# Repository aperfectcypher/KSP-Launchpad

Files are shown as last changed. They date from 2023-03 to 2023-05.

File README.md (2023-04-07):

# KSP-Launchpad
## THIS IS AN EARLY WORK IN PROGRESS

Firmware for the KSP-Launchpad board.

MCU is an ATmega2560.
## Features

* Dual 3-axis joystick for rotation and translation
* Linear potentiometers for throttle
* SAS LED
* RCS LED
* LED bars as ship ressources gauges
* LCD screen (128x32px) for ship status

## Schematics

The schematics are written using kicad.
The schematics are available in the `schematics` directory.

## License

The firmware and schematics are licensed under the Unlicense license.

## Author

[Aperfectcypher](https://github.com/aperfectcypher)

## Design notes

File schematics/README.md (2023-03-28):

# Schematics
The schematics are written using kicad.

Required libraries:
* [Connectors_JST](https://github.com/KiCad/Connectors_JST.pretty)

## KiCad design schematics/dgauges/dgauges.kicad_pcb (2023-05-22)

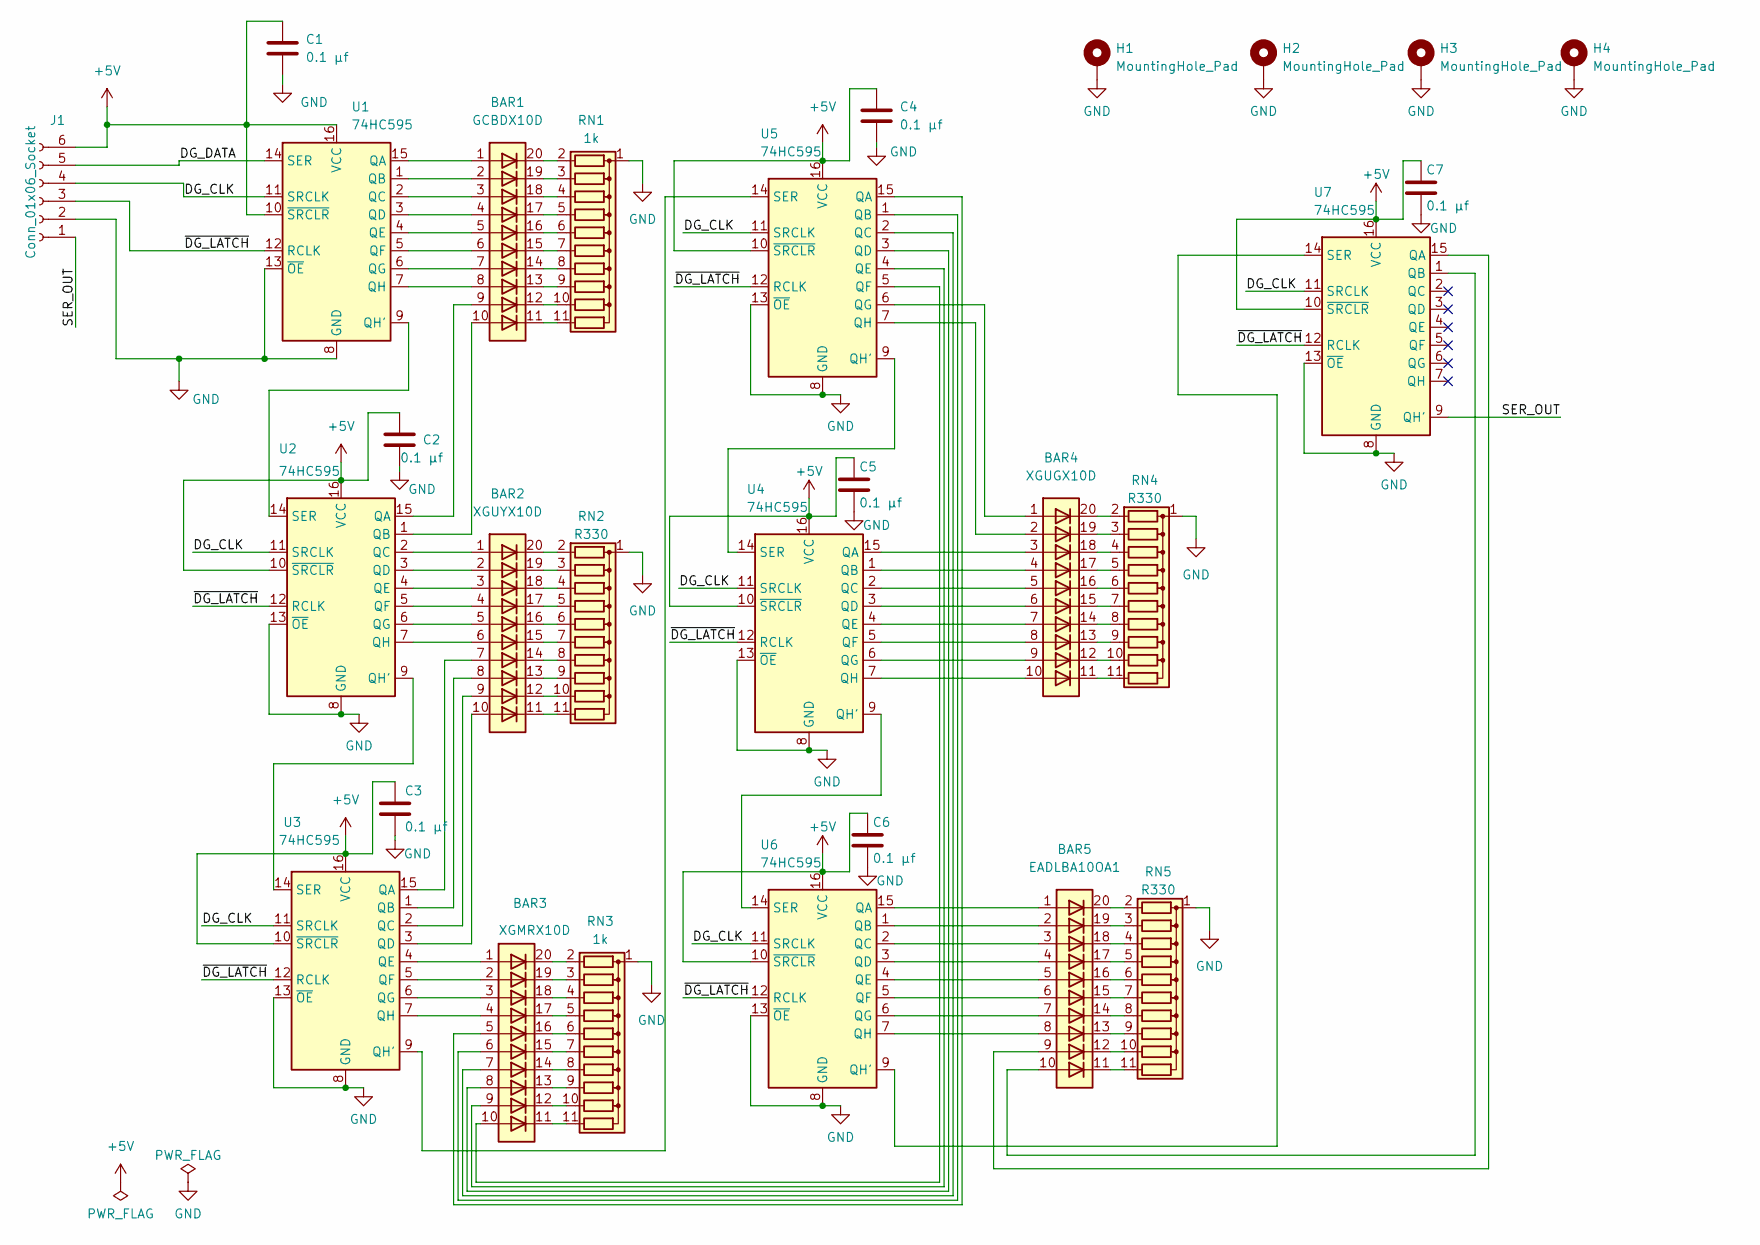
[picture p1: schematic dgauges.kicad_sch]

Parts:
BAR1: GCBDX10D; HDSP-4832
BAR2: XGUYX10D; HDSP-4832
BAR3: XGMRX10D; HDSP-4832
BAR4: XGUGX10D; HDSP-4832
BAR5: EADLBA10OA1; HDSP-4832
C1, C2, C3, C4, C5, C6, C7: 0.1 µf; C_Disc_D4.3mm_W1.9mm_P5.00mm; LCSC C254085
H1, H2, H3, H4: MountingHole_Pad; MountingHole_2.2mm_M2_ISO7380_Pad
J1: Conn_01x06_Socket; JST_PH_B6B-PH-K_1x06_P2.00mm_Vertical
RN1, RN3: 1k; R_Array_SIP11; digikey 4611X-101-102LF-ND
RN2, RN4, RN5: R330; R_Array_SIP11; digi-key 4611X-101-331LF
U1, U2, U3, U4, U5, U6, U7: 74HC595; DIP-16_W7.62mm

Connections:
+5V: C1.1, C2.1, C3.1, C4.1, C5.1, C6.1, C7.1, J1.6, U1.10 (~SRCLR), U1.16 (VCC), U2.10 (~SRCLR), U2.16 (VCC), U3.10 (~SRCLR), U3.16 (VCC), U4.10 (~SRCLR), U4.16 (VCC), U5.10 (~SRCLR), U5.16 (VCC), U6.10 (~SRCLR), U6.16 (VCC), U7.10 (~SRCLR), U7.16 (VCC)
/DG_CLK: J1.4, U1.11 (SRCLK), U2.11 (SRCLK), U3.11 (SRCLK), U4.11 (SRCLK), U5.11 (SRCLK), U6.11 (SRCLK), U7.11 (SRCLK)
/DG_DATA: J1.5, U1.14 (SER)
/SER_OUT: J1.1, U7.9 (QH')
/~DG_LATCH: J1.3, U1.12 (RCLK), U2.12 (RCLK), U3.12 (RCLK), U4.12 (RCLK), U5.12 (RCLK), U6.12 (RCLK), U7.12 (RCLK)
GND: C1.2, C2.2, C3.2, C4.2, C5.2, C6.2, C7.2, H1.1, H2.1, H3.1, H4.1, J1.2, RN1.1 (common), RN2.1 (common), RN3.1 (common), RN4.1 (common), RN5.1 (common), U1.8 (GND), U1.13 (~OE), U2.8 (GND), U2.13 (~OE), U3.8 (GND), U3.13 (~OE), U4.8 (GND), U4.13 (~OE), U5.8 (GND), U5.13 (~OE), U6.8 (GND), U6.13 (~OE), U7.8 (GND), U7.13 (~OE)
unnamed: BAR1.20 (K), RN1.2 (R1)
unnamed: BAR1.19 (K), RN1.3 (R2)
unnamed: BAR1.18 (K), RN1.4 (R3)
unnamed: BAR1.17 (K), RN1.5 (R4)
unnamed: BAR1.16 (K), RN1.6 (R5)
unnamed: BAR1.15 (K), RN1.7 (R6)
unnamed: BAR1.14 (K), RN1.8 (R7)
unnamed: BAR1.13 (K), RN1.9 (R8)
unnamed: BAR1.12 (K), RN1.10 (R9)
unnamed: BAR1.11 (K), RN1.11 (R10)
unnamed: BAR2.20 (K), RN2.2 (R1)
unnamed: BAR2.19 (K), RN2.3 (R2)
unnamed: BAR2.18 (K), RN2.4 (R3)
unnamed: BAR2.17 (K), RN2.5 (R4)
unnamed: BAR2.16 (K), RN2.6 (R5)
unnamed: BAR2.15 (K), RN2.7 (R6)
unnamed: BAR2.14 (K), RN2.8 (R7)
unnamed: BAR2.13 (K), RN2.9 (R8)
unnamed: BAR2.12 (K), RN2.10 (R9)
unnamed: BAR2.11 (K), RN2.11 (R10)
unnamed: BAR3.20 (K), RN3.2 (R1)
unnamed: BAR3.19 (K), RN3.3 (R2)
unnamed: BAR3.18 (K), RN3.4 (R3)
unnamed: BAR3.17 (K), RN3.5 (R4)
unnamed: BAR3.16 (K), RN3.6 (R5)
unnamed: BAR3.15 (K), RN3.7 (R6)
unnamed: BAR3.14 (K), RN3.8 (R7)
unnamed: BAR3.13 (K), RN3.9 (R8)
unnamed: BAR3.12 (K), RN3.10 (R9)
unnamed: BAR3.11 (K), RN3.11 (R10)
unnamed: BAR4.20 (K), RN4.2 (R1)
unnamed: BAR4.19 (K), RN4.3 (R2)
unnamed: BAR4.18 (K), RN4.4 (R3)
unnamed: BAR4.17 (K), RN4.5 (R4)
unnamed: BAR4.16 (K), RN4.6 (R5)
unnamed: BAR4.15 (K), RN4.7 (R6)
unnamed: BAR4.14 (K), RN4.8 (R7)
unnamed: BAR4.13 (K), RN4.9 (R8)
unnamed: BAR4.12 (K), RN4.10 (R9)
unnamed: BAR4.11 (K), RN4.11 (R10)
unnamed: BAR5.20 (K), RN5.2 (R1)
unnamed: BAR5.19 (K), RN5.3 (R2)
unnamed: BAR5.18 (K), RN5.4 (R3)
unnamed: BAR5.17 (K), RN5.5 (R4)
unnamed: BAR5.16 (K), RN5.6 (R5)
unnamed: BAR5.15 (K), RN5.7 (R6)
unnamed: BAR5.14 (K), RN5.8 (R7)
unnamed: BAR5.13 (K), RN5.9 (R8)
unnamed: BAR5.12 (K), RN5.10 (R9)
unnamed: BAR5.11 (K), RN5.11 (R10)
unnamed: BAR1.1 (A), U1.15 (QA)
unnamed: BAR1.2 (A), U1.1 (QB)
unnamed: BAR1.3 (A), U1.2 (QC)
unnamed: BAR1.4 (A), U1.3 (QD)
unnamed: BAR1.5 (A), U1.4 (QE)
unnamed: BAR1.6 (A), U1.5 (QF)
unnamed: BAR1.7 (A), U1.6 (QG)
unnamed: U1.9 (QH'), U2.14 (SER)
unnamed: BAR1.8 (A), U1.7 (QH)
unnamed: BAR1.9 (A), U2.15 (QA)
unnamed: BAR1.10 (A), U2.1 (QB)
unnamed: BAR2.1 (A), U2.2 (QC)
unnamed: BAR2.2 (A), U2.3 (QD)
unnamed: BAR2.3 (A), U2.4 (QE)
unnamed: BAR2.4 (A), U2.5 (QF)
unnamed: BAR2.5 (A), U2.6 (QG)
unnamed: U2.9 (QH'), U3.14 (SER)
unnamed: BAR2.6 (A), U2.7 (QH)
unnamed: BAR2.7 (A), U3.15 (QA)
unnamed: BAR2.8 (A), U3.1 (QB)
unnamed: BAR2.9 (A), U3.2 (QC)
unnamed: BAR2.10 (A), U3.3 (QD)
unnamed: BAR3.1 (A), U3.4 (QE)
unnamed: BAR3.2 (A), U3.5 (QF)
unnamed: BAR3.3 (A), U3.6 (QG)
unnamed: U3.9 (QH'), U5.14 (SER)
unnamed: BAR3.4 (A), U3.7 (QH)
unnamed: BAR4.3 (A), U4.15 (QA)
unnamed: BAR4.4 (A), U4.1 (QB)
unnamed: BAR4.5 (A), U4.2 (QC)
unnamed: BAR4.6 (A), U4.3 (QD)
unnamed: BAR4.7 (A), U4.4 (QE)
unnamed: BAR4.8 (A), U4.5 (QF)
unnamed: BAR4.9 (A), U4.6 (QG)
unnamed: U4.9 (QH'), U6.14 (SER)
unnamed: BAR4.10 (A), U4.7 (QH)
unnamed: U4.14 (SER), U5.9 (QH')
unnamed: BAR3.5 (A), U5.15 (QA)
unnamed: BAR3.6 (A), U5.1 (QB)
unnamed: BAR3.7 (A), U5.2 (QC)
unnamed: BAR3.8 (A), U5.3 (QD)
unnamed: BAR3.9 (A), U5.4 (QE)
unnamed: BAR3.10 (A), U5.5 (QF)
unnamed: BAR4.1 (A), U5.6 (QG)
unnamed: BAR4.2 (A), U5.7 (QH)
unnamed: BAR5.1 (A), U6.15 (QA)
unnamed: BAR5.2 (A), U6.1 (QB)
unnamed: BAR5.3 (A), U6.2 (QC)
unnamed: BAR5.4 (A), U6.3 (QD)
unnamed: BAR5.5 (A), U6.4 (QE)
unnamed: BAR5.6 (A), U6.5 (QF)
unnamed: BAR5.7 (A), U6.6 (QG)
unnamed: U6.9 (QH'), U7.14 (SER)
unnamed: BAR5.8 (A), U6.7 (QH)
unnamed: BAR5.9 (A), U7.15 (QA)
unnamed: BAR5.10 (A), U7.1 (QB)

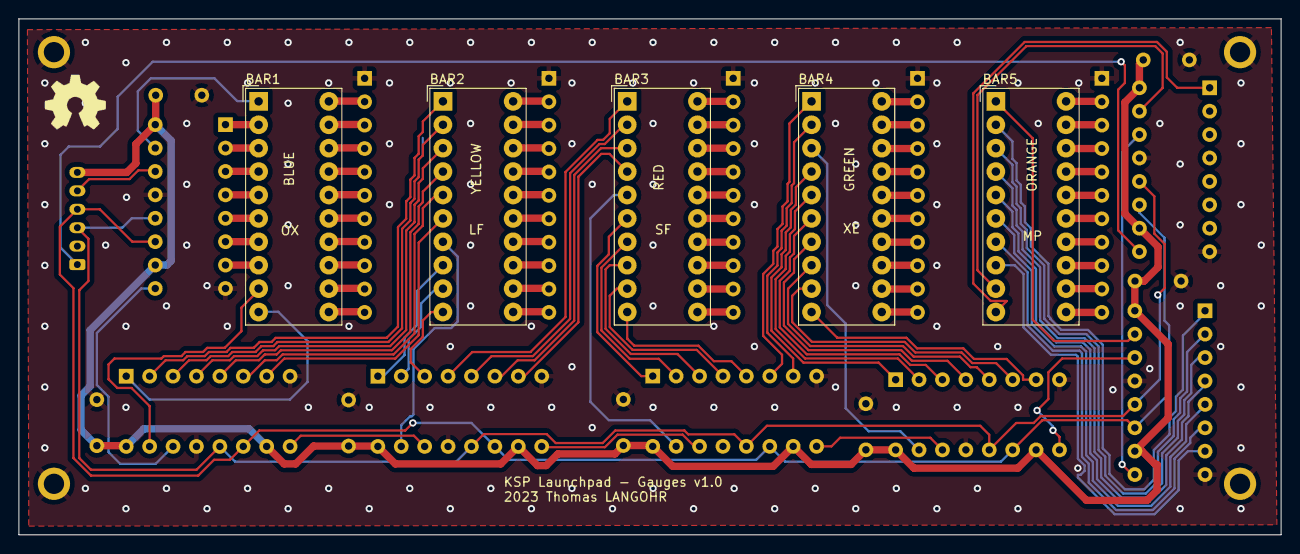
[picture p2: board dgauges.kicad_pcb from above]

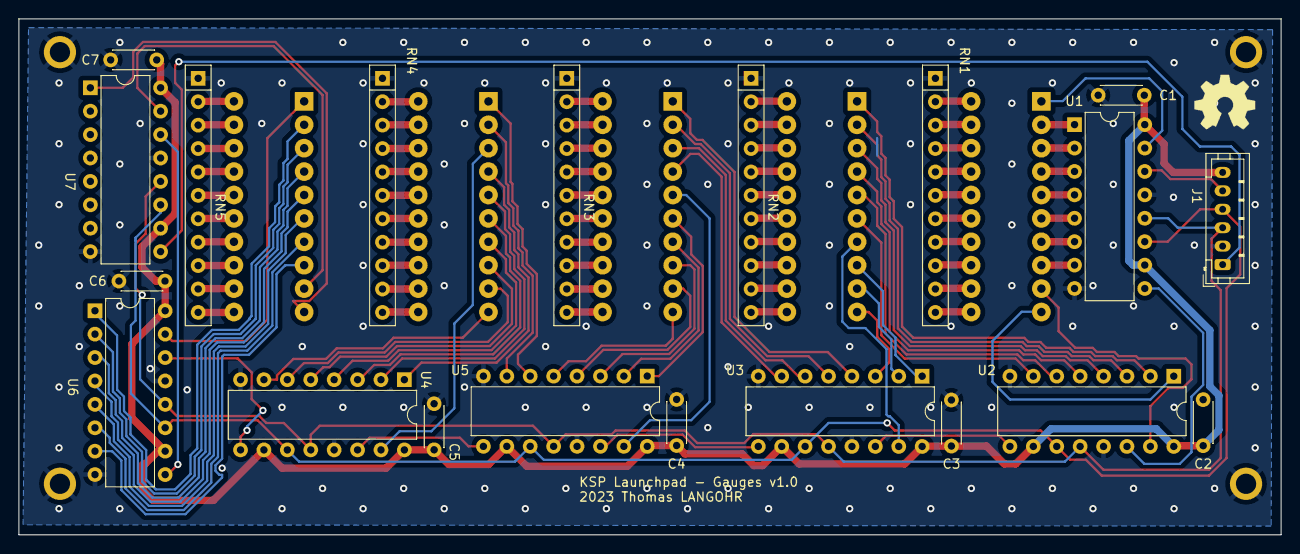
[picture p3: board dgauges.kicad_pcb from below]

Board: 2 copper layers, 137.0 x 56.0 mm, 29 parts (20 on the bottom side), 112 nets.

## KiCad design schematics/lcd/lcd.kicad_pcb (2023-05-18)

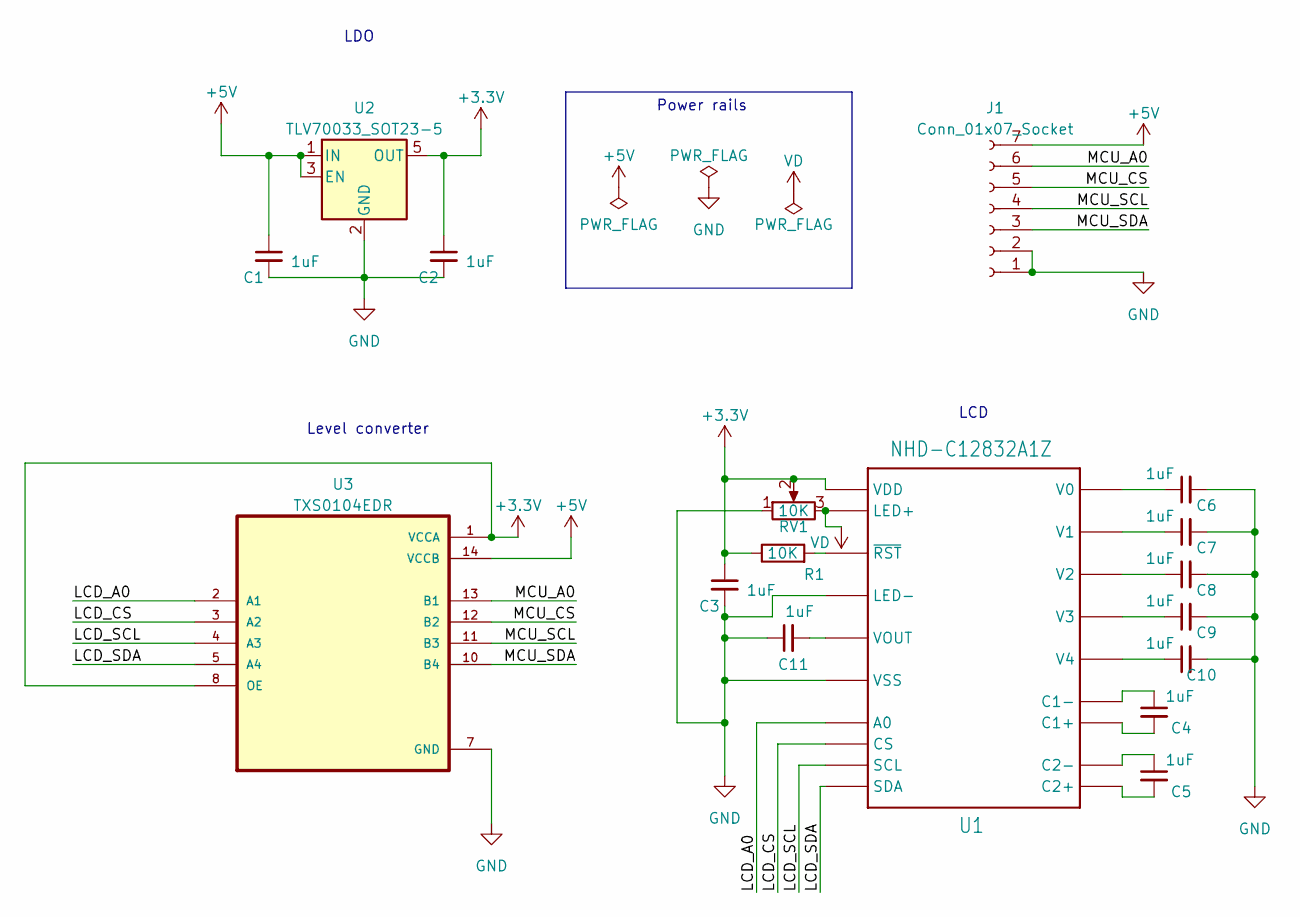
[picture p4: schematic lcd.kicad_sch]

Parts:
C1, C2, C3, C4, C5, C6, C7, C8, C9, C10, C11: 1uF; C_0603_1608Metric; lcsc C59302
J1: Conn_01x07_Socket; JST_PH_B7B-PH-K_1x07_P2.00mm_Vertical
R1: 10K; R_0603_1608Metric; lcsc C25804
RV1: 10K; Potentiometer_Bourns_3314G_Vertical; lcsc C780220
U1: NHD-C12832A1Z; JLCPCB BOM 0
U2: TLV70033_SOT23-5; SOT-23-5
U3: TXS0104EDR; SOIC127P600X175-14N; LCSC C79342

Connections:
+3.3V: C2.1, C3.1, R1.1, RV1.2, U1.P12 (VDD), U2.5 (OUT), U3.1 (VCCA), U3.8 (OE)
+5V: C1.1, J1.7, U2.1 (IN), U2.3 (EN), U3.14 (VCCB)
/LCD_A0: U1.P15 (A0), U3.2 (A1)
/LCD_CS: U1.P17 (CS), U3.3 (A2)
/LCD_SCL: U1.P14 (SCL), U3.4 (A3)
/LCD_SDA: U1.P13 (SDA), U3.5 (A4)
/MCU_A0: J1.6, U3.13 (B1)
/MCU_CS: J1.5, U3.12 (B2)
/MCU_SCL: J1.4, U3.11 (B3)
/MCU_SDA: J1.3, U3.10 (B4)
GND: C1.2, C2.2, C3.2, C6.2, C7.2, C8.2, C9.2, C10.2, C11.1, J1.1, J1.2, RV1.1, U1.P11 (VSS), U1.P19 (LED-), U2.2 (GND), U3.7 (GND)
unnamed: C4.2, U1.P8 (C1+)
unnamed: C4.1, U1.P9 (C1-)
unnamed: C5.2, U1.P7 (C2+)
unnamed: C5.1, U1.P6 (C2-)
unnamed: C6.1, U1.P1 (V0)
unnamed: C7.1, U1.P2 (V1)
unnamed: C8.1, U1.P3 (V2)
unnamed: C9.1, U1.P4 (V3)
unnamed: C10.1, U1.P5 (V4)
unnamed: C11.2, U1.P10 (VOUT)
unnamed: R1.2, U1.P16 (~RST)
VD: RV1.3, U1.P18 (LED+)

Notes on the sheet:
LCD
Level converter
Power rails
LDO

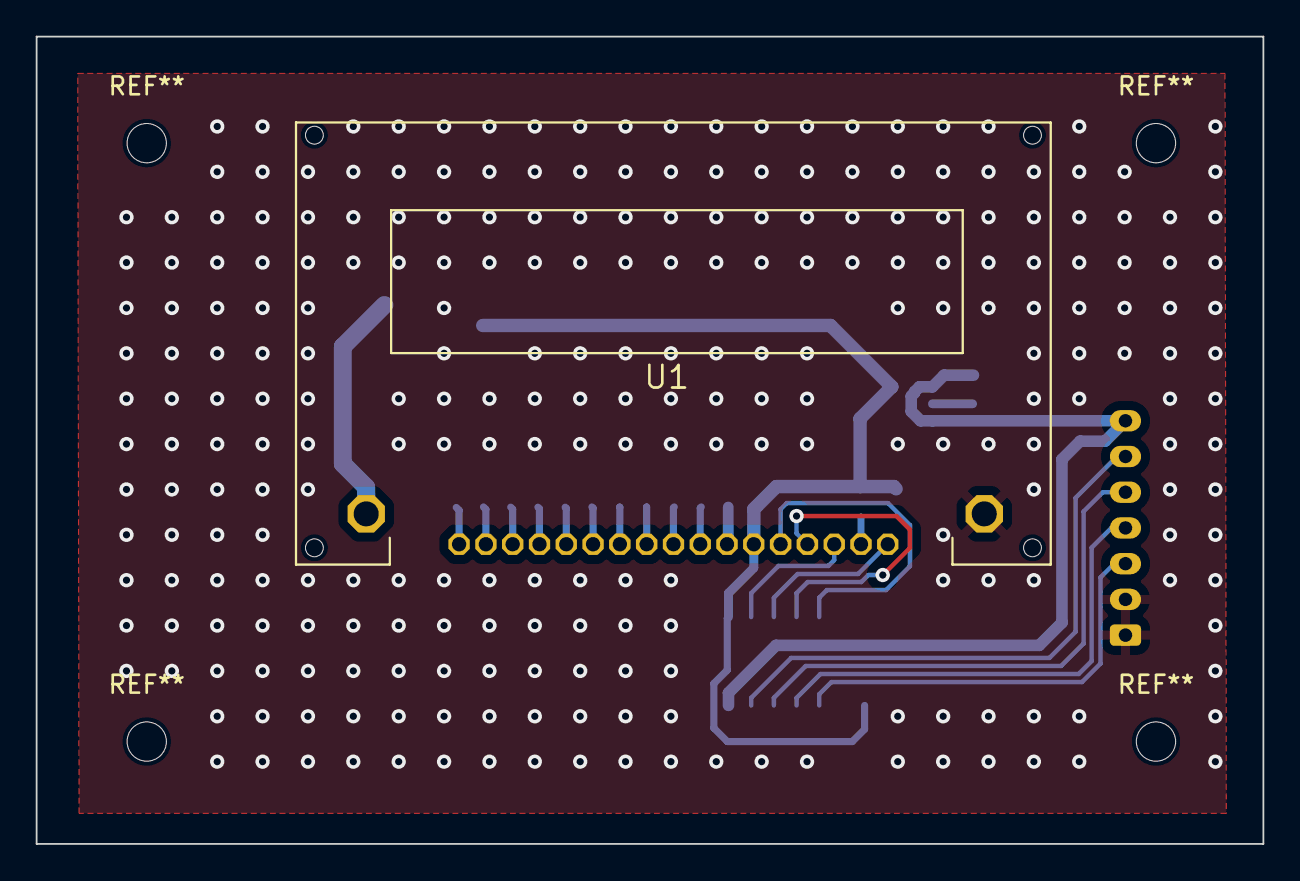
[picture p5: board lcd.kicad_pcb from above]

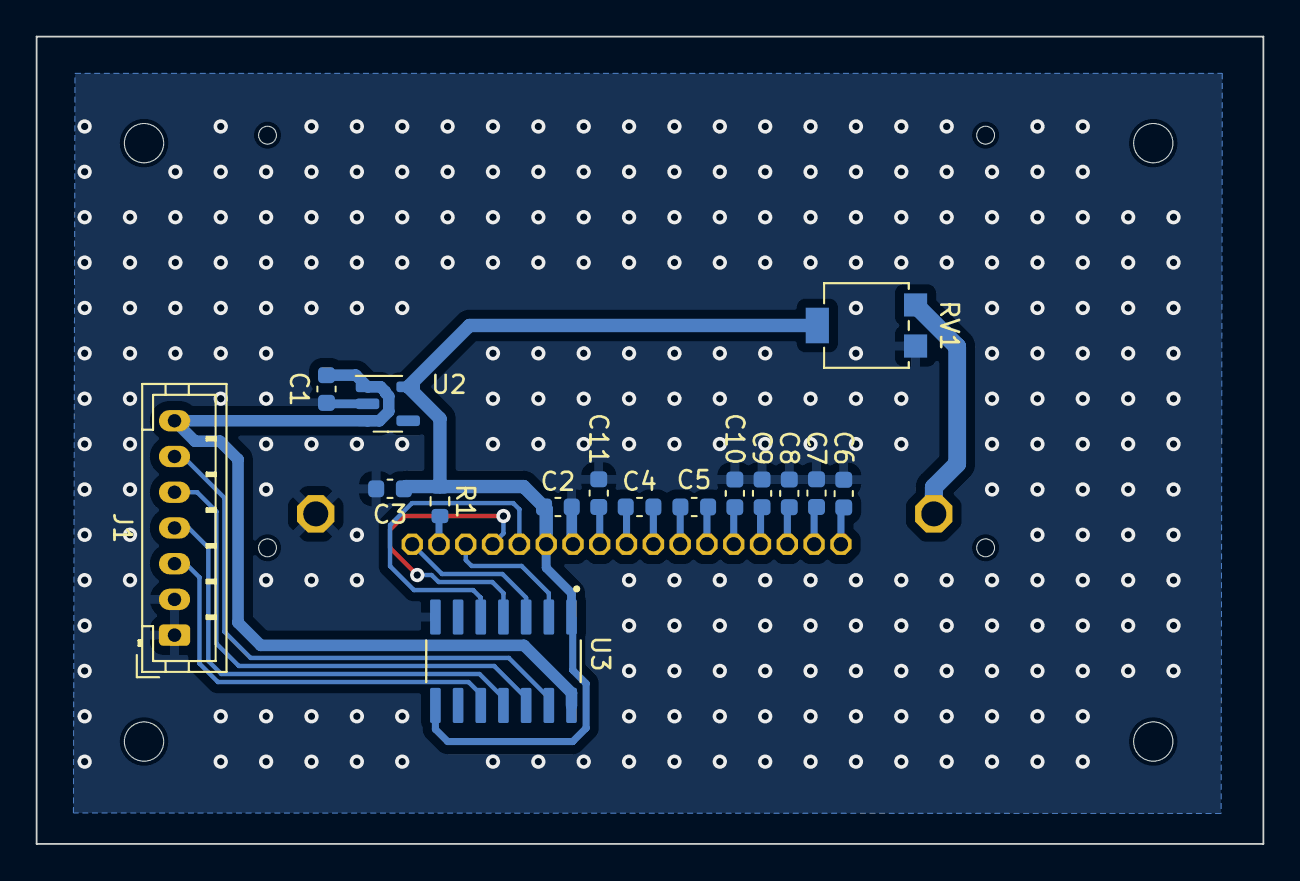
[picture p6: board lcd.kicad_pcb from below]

Board: 2 copper layers, 68.7 x 45.2 mm, 17 parts (16 on the bottom side), 23 nets.

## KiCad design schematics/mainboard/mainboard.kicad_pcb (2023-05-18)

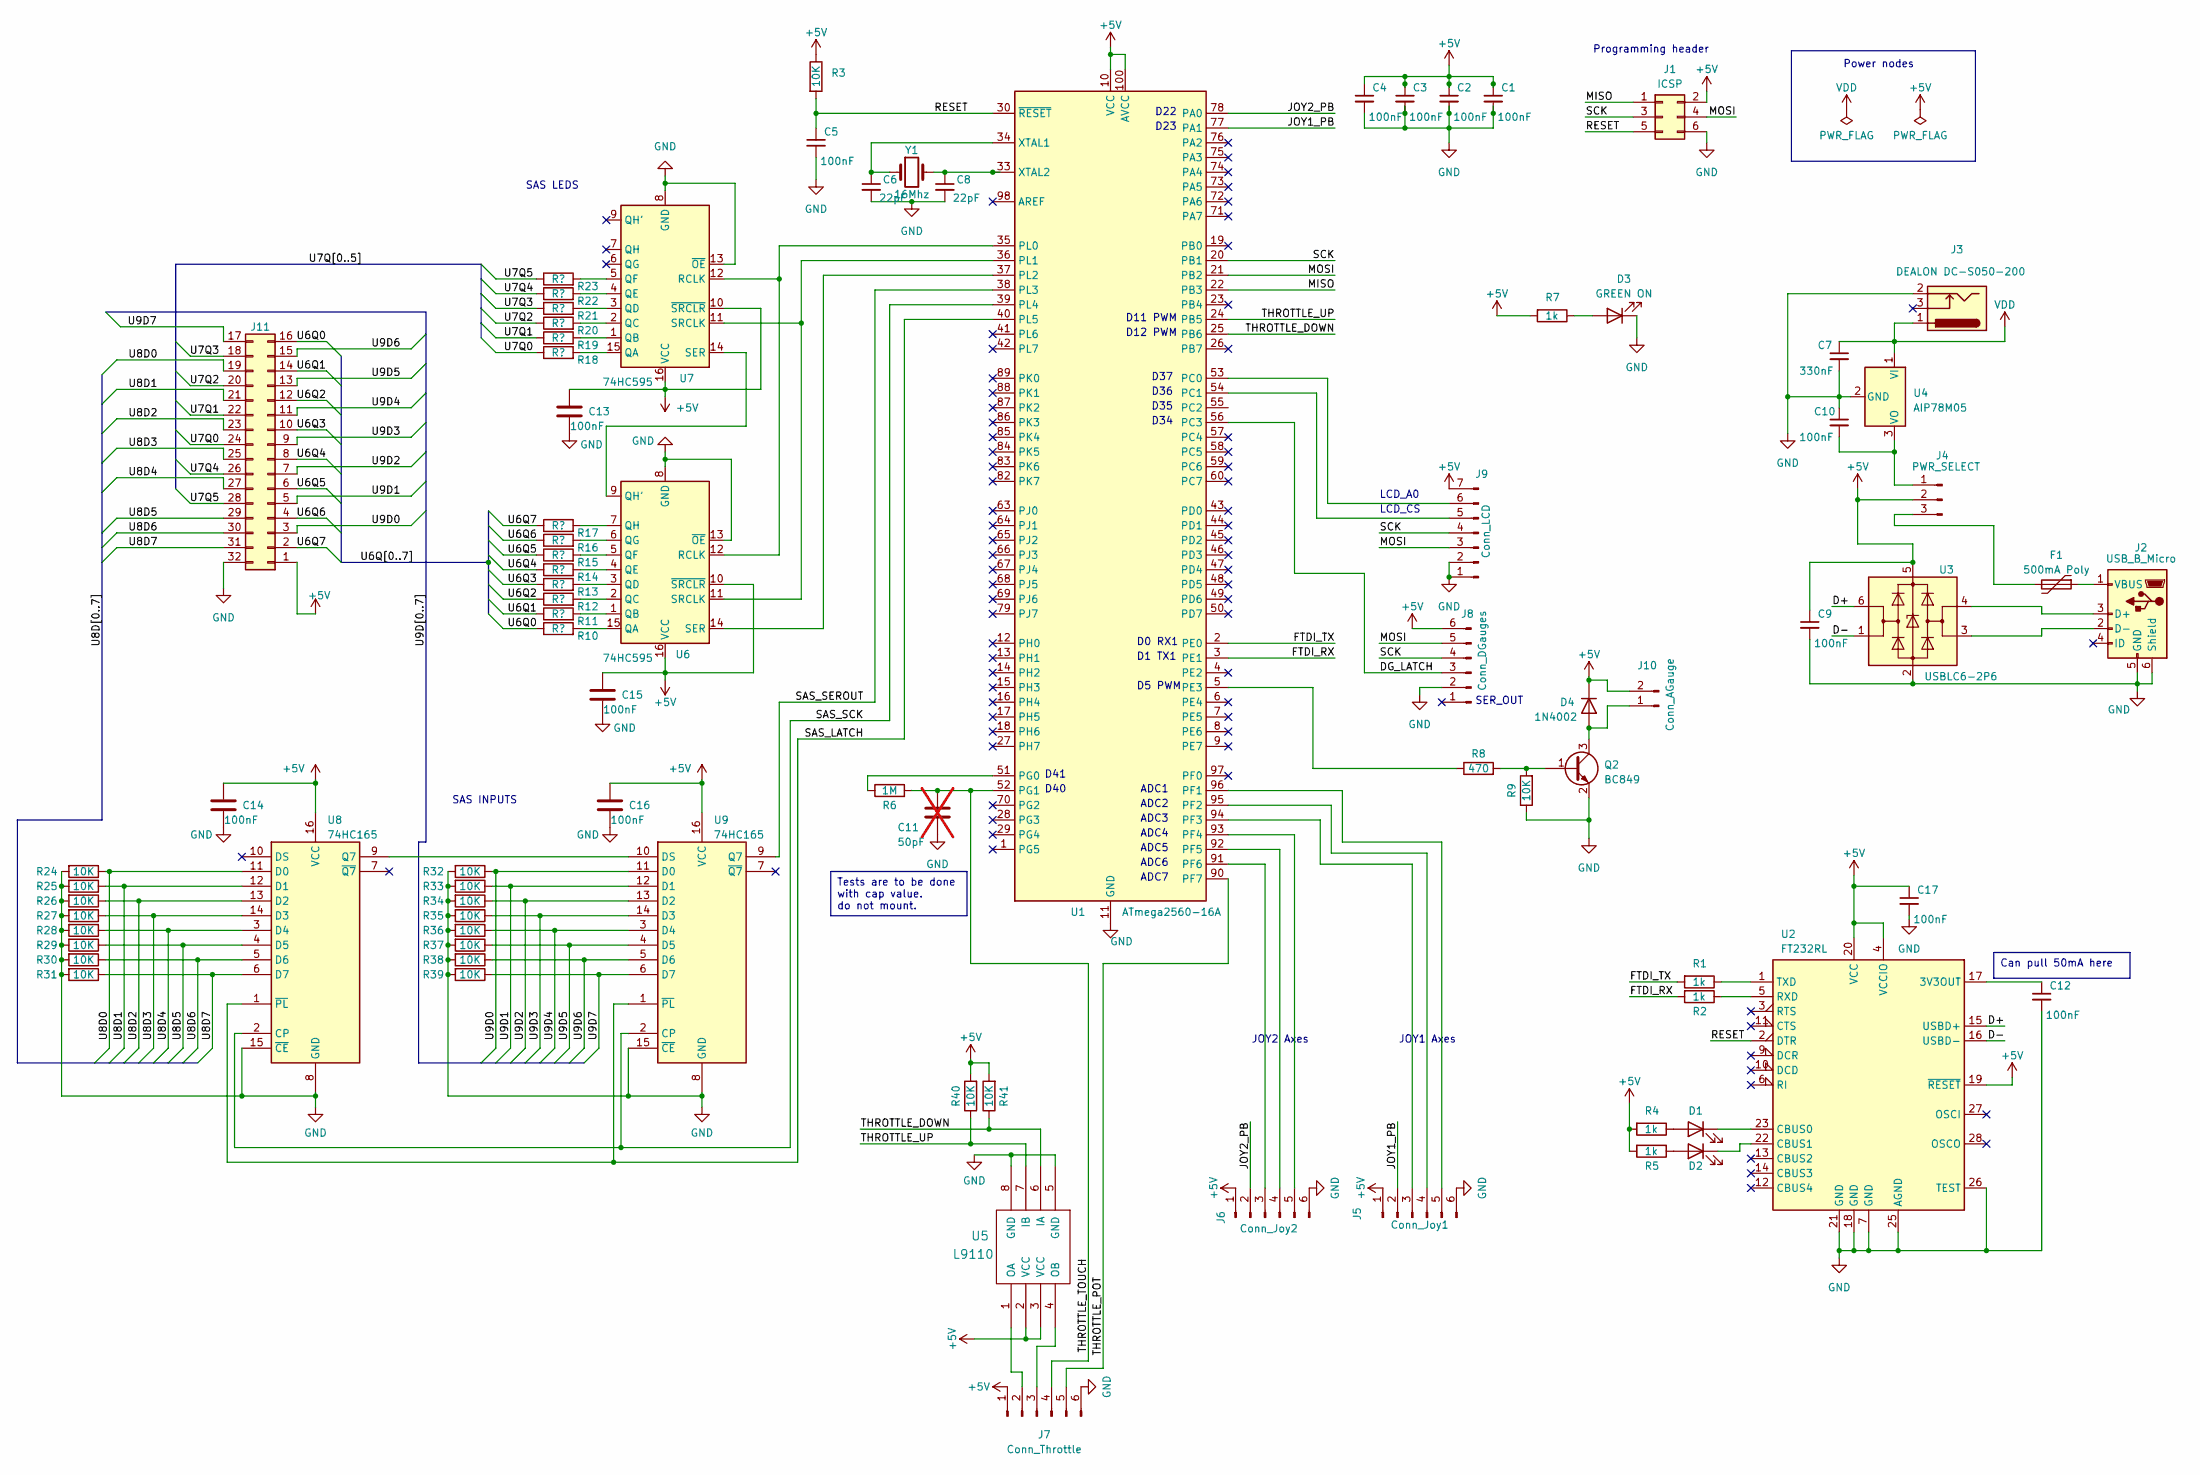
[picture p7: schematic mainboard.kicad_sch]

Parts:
C1, C2, C3, C4, C5, C9, C12, C17: 100nF; C_0603_1608Metric; lcsc C30926
C6, C8: 22pF; C_0603_1608Metric; lcsc C105620
C7: 330nF; C_0603_1608Metric; lcsc C282682
C10: 100nF; C_0603_1608Metric; lcsc C14665
C11: 50pF; C_0603_1608Metric; not fitted
C13, C14, C15, C16: 100nF; C_0603_1608Metric
D1, D2: LED; LED_1206_3216Metric
D3: GREEN ON; LED_0603_1608Metric
D4: 1N4002; D_SOD-123F; lcsc C169542
F1: 500mA Poly; Fuse_0603_1608Metric; lcsc C311055
J1: ICSP; PinHeader_2x03_P2.54mm_Vertical
J2: USB_B_Micro; USB_Micro-B_Molex-105017-0001; lcsc C962222
J3: DEALON DC-S050-200; BarrelJack_CLIFF_FC681465S_SMT_Horizontal; lcsc C2936010
J4: PWR_SELECT; PinHeader_1x03_P2.54mm_Vertical
J5: Conn_Joy1; JST_PH_B6B-PH-K_1x06_P2.00mm_Vertical
J6: Conn_Joy2; JST_PH_B6B-PH-K_1x06_P2.00mm_Vertical
J7: Conn_Throttle; JST_PH_B6B-PH-K_1x06_P2.00mm_Vertical
J8: Conn_DGauges; JST_PH_B6B-PH-K_1x06_P2.00mm_Vertical
J9: Conn_LCD; JST_PH_B7B-PH-K_1x07_P2.00mm_Vertical
J10: Conn_AGauge; JST_PH_B2B-PH-K_1x02_P2.00mm_Vertical
J11: Conn_SAS; JST_PHD_B32B-PHDSS_2x16_P2.00mm_Vertical; lcsc C1121898
Q2: BC849; SOT-23; lcsc C475633
R1, R2, R4, R5, R7: 1k; R_0603_1608Metric; lcsc C21190
R3: 10K; R_0603_1608Metric; lcsc C25804
R6: 1M; R_0603_1608Metric
R8: 470; R_0603_1608Metric
R9, R24, R25, R26, R27, R28, R29, R30, R31, R32, R33, R34, R35, R36, R37, R38, R39, R40, R41: 10K; R_0603_1608Metric
R10, R11, R12, R13, R14, R15, R16, R17, R18, R19, R20, R21, R22, R23: R?; R_0603_1608Metric
U1: ATmega2560-16A; TQFP-100_14x14mm_P0.5mm; lcsc C22460
U2: FT232RL; SSOP-28_3.9x9.9mm_P0.635mm
U3: USBLC6-2P6; SOT-666; lcsc C15999
U4: AIP78M05; TO-252-2; lcsc C3019178
U5: L9110; DIP-8_W7.62mm_Socket
U6, U7: 74HC595; DIP-16_W7.62mm
U8, U9: 74HC165; DIP-16_W7.62mm
Y1: 16Mhz; Crystal_SMD_5032-2Pin_5.0x3.2mm; lcsc C112572

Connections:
+5V: C1.1, C2.1, C3.1, C4.1, C9.1, C13.1, C14.1, C15.1, C16.1, C17.1, D4.1 (K), J1.2, J4.2, J5.1, J6.1, J7.1, J8.6, J9.7, J10.2, J11.1, R3.1, R4.2, R5.2, R7.2, R40.2, R41.2, U1.10 (VCC), U1.31 (VCC), U1.61 (VCC), U1.80 (VCC), U1.100 (AVCC), U2.4 (VCCIO), U2.19 (~RESET), U2.20 (VCC), U3.5 (VBUS), U5.2 (VCC), U5.3 (VCC), U6.10 (~SRCLR), U6.16 (VCC), U7.10 (~SRCLR), U7.16 (VCC), U8.16 (VCC), U9.16 (VCC)
/D+: U2.15 (USBD+), U3.6 (I/O1)
/D-: U2.16 (USBD-), U3.1 (I/O1)
/DG_LATCH: J8.3, U1.56 (PC3)
/FTDI_RX: R2.2, U1.3 (PE1)
/FTDI_TX: R1.2, U1.2 (PE0)
/JOY1_PB: J5.2, U1.77 (PA1)
/JOY2_PB: J6.2, U1.78 (PA0)
/MISO: J1.1, U1.22 (PB3)
/MOSI: J1.4, J8.5, J9.3, U1.21 (PB2)
/RESET: C5.1, J1.5, R3.2, U1.30 (~RESET), U2.2 (DTR)
/SAS_LATCH: U1.40 (PL5), U8.1 (~PL), U9.1 (~PL)
/SAS_SCK: U1.39 (PL4), U8.2 (CP), U9.2 (CP)
/SAS_SEROUT: U1.38 (PL3), U9.9 (Q7)
/SCK: J1.3, J8.4, J9.4, U1.20 (PB1)
/THROTTLE_DOWN: R41.1, U1.25 (PB6), U5.6 (IA)
/THROTTLE_POT: J7.5, U1.90 (PF7)
/THROTTLE_TOUCH: C11.1, J7.4, R6.2, U1.52 (PG1)
/THROTTLE_UP: R40.1, U1.24 (PB5), U5.7 (IB)
/U6Q0: J11.16, R10.1
/U6Q1: J11.14, R11.1
/U6Q2: J11.12, R12.1
/U6Q3: J11.10, R13.1
/U6Q4: J11.8, R14.1
/U6Q5: J11.6, R15.1
/U6Q6: J11.4, R16.1
/U6Q7: J11.2, R17.1
/U7Q0: J11.24, R18.1
/U7Q1: J11.22, R19.1
/U7Q2: J11.20, R20.1
/U7Q3: J11.18, R21.1
/U7Q4: J11.26, R22.1
/U7Q5: J11.28, R23.1
/U8D0: J11.19, R24.1, U8.11 (D0)
/U8D1: J11.21, R25.1, U8.12 (D1)
/U8D2: J11.23, R26.1, U8.13 (D2)
/U8D3: J11.25, R27.1, U8.14 (D3)
/U8D4: J11.27, R28.1, U8.3 (D4)
/U8D5: J11.29, R29.1, U8.4 (D5)
/U8D6: J11.30, R30.1, U8.5 (D6)
/U8D7: J11.31, R31.1, U8.6 (D7)
/U9D0: J11.3, R32.1, U9.11 (D0)
/U9D1: J11.5, R33.1, U9.12 (D1)
/U9D2: J11.7, R34.1, U9.13 (D2)
/U9D3: J11.9, R35.1, U9.14 (D3)
/U9D4: J11.11, R36.1, U9.3 (D4)
/U9D5: J11.13, R37.1, U9.4 (D5)
/U9D6: J11.15, R38.1, U9.5 (D6)
/U9D7: J11.17, R39.1, U9.6 (D7)
GND: C1.2, C2.2, C3.2, C4.2, C5.2, C6.2, C7.2, C8.2, C9.2, C10.1, C11.2, C12.2, C13.2, C14.2, C15.2, C16.2, C17.2, D3.1 (K), J1.6, J2.5 (GND), J2.6 (Shield), J3.2, J5.6, J6.6, J7.6, J8.2, J9.1, J9.2, J11.32, Q2.2 (E), R9.1, R24.2, R25.2, R26.2, R27.2, R28.2, R29.2, R30.2, R31.2, R32.2, R33.2, R34.2, R35.2, R36.2, R37.2, R38.2, R39.2, U1.11 (GND), U1.32 (GND), U1.62 (GND), U1.81 (GND), U1.99 (GND), U2.7 (GND), U2.18 (GND), U2.21 (GND), U2.25 (AGND), U2.26 (TEST), U3.2 (GND), U4.2 (GND), U5.5 (GND), U5.8 (GND), U6.8 (GND), U6.13 (~OE), U7.8 (GND), U7.13 (~OE), U8.8 (GND), U8.15 (~CE), U9.8 (GND), U9.15 (~CE)
unnamed: D1.2 (A), R4.1
unnamed: D1.1 (K), U2.23 (CBUS0)
unnamed: D2.2 (A), R5.1
unnamed: D2.1 (K), U2.22 (CBUS1)
unnamed: D3.2 (A), R7.1
unnamed: D4.2 (A), J10.1, Q2.3 (C)
unnamed: J2.3 (D+), U3.4 (I/O2)
unnamed: J2.2 (D-), U3.3 (I/O2)
unnamed: F1.1, J2.1 (VBUS)
unnamed: C10.2, J4.1, U4.3 (VO)
unnamed: F1.2, J4.3
unnamed: J5.3, U1.94 (PF3)
unnamed: J5.4, U1.95 (PF2)
unnamed: J5.5, U1.96 (PF1)
unnamed: J6.3, U1.91 (PF6)
unnamed: J6.4, U1.92 (PF5)
unnamed: J6.5, U1.93 (PF4)
unnamed: J7.2, U5.1 (OA)
unnamed: J7.3, U5.4 (OB)
unnamed: J9.5, U1.54 (PC1)
unnamed: J9.6, U1.53 (PC0)
unnamed: Q2.1 (B), R8.2, R9.2
unnamed: R8.1, U1.5 (PE3)
unnamed: R6.1, U1.51 (PG0)
unnamed: U1.35 (PL0), U6.12 (RCLK), U7.12 (RCLK)
unnamed: U1.36 (PL1), U6.11 (SRCLK), U7.11 (SRCLK)
unnamed: U1.37 (PL2), U6.14 (SER)
unnamed: C6.1, U1.34 (XTAL1), Y1.1
unnamed: C8.1, U1.33 (XTAL2), Y1.2
unnamed: C12.1, U2.17 (3V3OUT)
unnamed: R2.1, U2.5 (RXD)
unnamed: R1.1, U2.1 (TXD)
unnamed: R10.2, U6.15 (QA)
unnamed: R11.2, U6.1 (QB)
unnamed: R12.2, U6.2 (QC)
unnamed: R13.2, U6.3 (QD)
unnamed: R14.2, U6.4 (QE)
unnamed: R15.2, U6.5 (QF)
unnamed: R16.2, U6.6 (QG)
unnamed: U6.9 (QH'), U7.14 (SER)
unnamed: R17.2, U6.7 (QH)
unnamed: R18.2, U7.15 (QA)
unnamed: R19.2, U7.1 (QB)
unnamed: R20.2, U7.2 (QC)
unnamed: R21.2, U7.3 (QD)
unnamed: R22.2, U7.4 (QE)
unnamed: R23.2, U7.5 (QF)
unnamed: U8.9 (Q7), U9.10 (DS)
VDD: C7.1, J3.1, U4.1 (VI)

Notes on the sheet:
Tests are to be done with cap value. do not mount.
Can pull 50mA here
ADC3
D37
SAS INPUTS
D36
ADC6
D0 RX1
LCD_A0
D12 PWM
D35
D34
D22
ADC2
ADC7
SER_OUT
ADC4
ADC5
LCD_CS
D40
Programming header
D1 TX1
D23
D11 PWM
D41
JOY2 Axes
SAS LEDS
Power nodes
D5 PWM
JOY1 Axes
ADC1

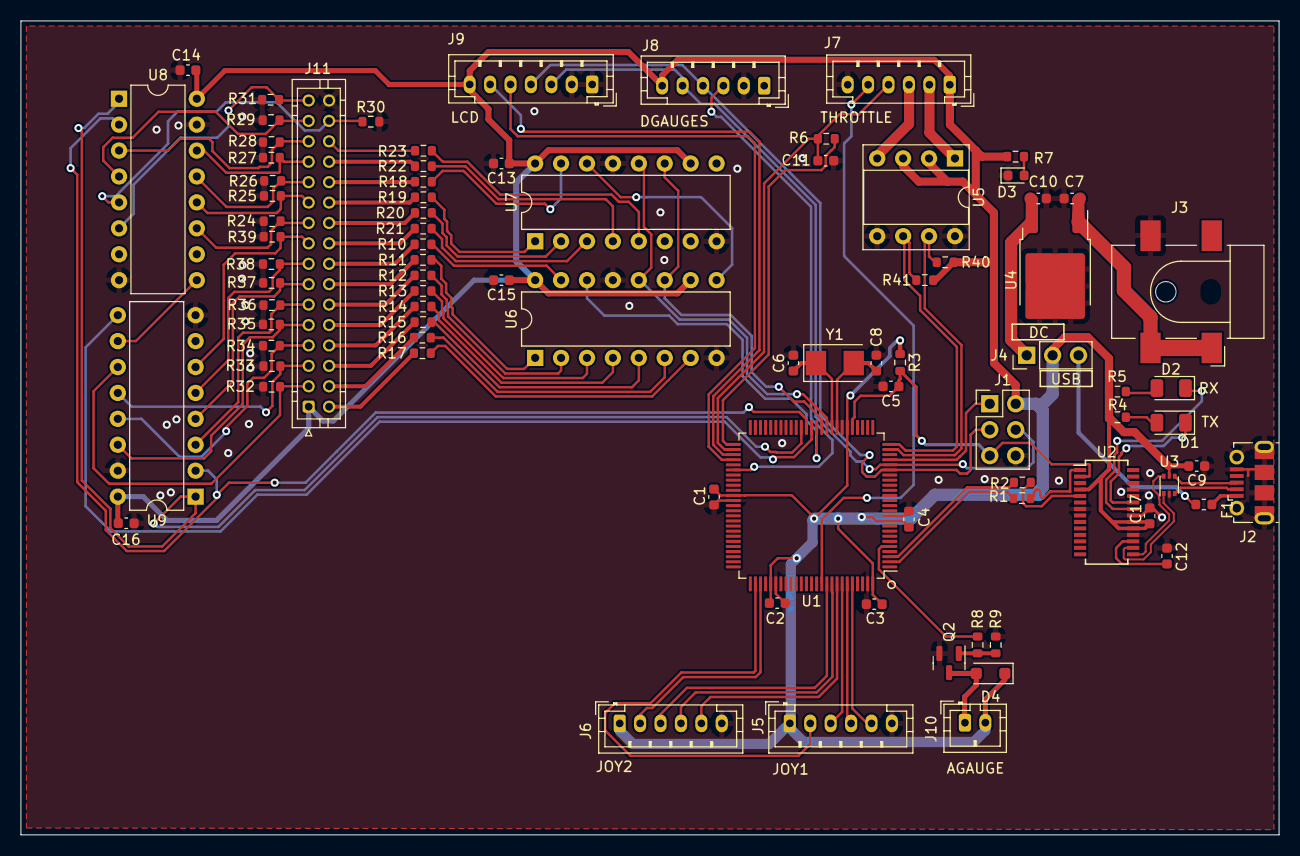
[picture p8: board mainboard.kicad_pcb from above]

Board: 2 copper layers, 123.3 x 79.8 mm, 85 parts (0 on the bottom side), 99 nets.

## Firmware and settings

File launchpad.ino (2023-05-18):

#include "KerbalSimpit.h"
#include <SPI.h>
#include <U8g2lib.h>
#include <CapacitiveSensor.h>

// ============Defines============

// Types
typedef uint32_t dword;
typedef int32_t sdword;
typedef uint16_t word;
typedef int16_t sword;
typedef uint8_t byte;
typedef int8_t sbyte;

// LCD display modes
#define NB_LCD_DISPLAY_MODES          2
#define LCD_DISPLAY_MODE_IDLE         -1
#define LCD_DISPLAY_MODE_CONNECTED    -2
#define LCD_DISPLAY_MODE_APSIDES      0
#define LCD_DISPLAY_MODE_ALT          1


// -----------Pins----------------
// LEDs
#define RCS_LED_PIN       30
#define SAS_LED_PIN       31

// Throttle
#define THROTTLE_INPUT_PIN         PIN_A7
#define THROTTLE_MOT_FWD_PIN       11
#define THROTTLE_MOT_REV_PIN       12
#define THROTTLE_TOUCH_SEND_PIN    51
#define THROTTLE_TOUCH_RECV_PIN    52
/* PLACEHOLDER TODO CORRECT PIN & NAME */
#define pb1                        24
#define pb2                        25

// Joystick 1
#define JOY1_X_PIN         PIN_A1
#define JOY1_Y_PIN         PIN_A2
#define JOY1_Z_PIN         PIN_A3
#define JOY1_PB_PIN        22

// Joystick 2
#define JOY2_X_PIN         PIN_A4
#define JOY2_Y_PIN         PIN_A5
#define JOY2_Z_PIN         PIN_A6
#define JOY2_PB_PIN        23

// Digital gauges
#define DGAUGES_LATCH_PIN  34
//      DGAUGES_DATA_PIN   21 /* DATA/CLK = ATmega2560 SPI */
//      DGAUGES_CLOCK_PIN  20

// Analog gauge
#define AGAUGE_EC_PIN      13

// LCD Display
#define LCD_DISPLAY_CS_PIN          36
#define LCD_DISPLAY_A0_PIN          37
//      LCD_DISPLAY_SDA_PIN         21 /* DATA/CLK = ATmega2560 SPI */
//      LCD_DISPLAY_SCL_PIN         20
#define LCD_DISPLAY_MODE_UP_PIN     2
#define LCD_DISPLAY_MODE_DOWN_PIN   3
// -------------------------------

// -----------Settings-----------
// Joystick
#define JOY_DEADZONE 1500

// Digital gauges
#define NB_DGAUGES 1
#define DGAUGES_OX 0

// Throttle
#define THROTTLE_MOT_TORQUE 255u // 0-255, pwm value
#define THROTTLE_TOUCH_THRESHOLD 35u
// ------------------------------

// Declare a KerbalSimpit object that will
// communicate using the "Serial" device.
KerbalSimpit simpitClient(Serial);

// LCD Display (Hardware SPI, CS=5, A0=7)
U8G2_ST7565_NHD_C12832_F_4W_HW_SPI u8g2(U8G2_R2, LCD_DISPLAY_CS_PIN, LCD_DISPLAY_A0_PIN);
char lcdLine1_ba[16] = {0};
char lcdLine2_ba[16] = {0};

// Create a SPI settings object for the digital gauges
SPISettings dgaugesSpi(10000000UL, MSBFIRST, SPI_MODE0);

// Create a CapacitiveSensor object for the throttle
CapacitiveSensor throttleTouchSensor(THROTTLE_TOUCH_SEND_PIN, THROTTLE_TOUCH_RECV_PIN);

// ---- Globals ----
// Ship fuel tanks in percent
byte shipFuelPercent_ba[NB_DGAUGES] = {0};
// Ship electric charge percent mapped on a byte (0-100%/0-255)
byte shipECPercent_b = 0;
// LCD display mode
sbyte lcdDisplayMode_sb = LCD_DISPLAY_MODE_IDLE;
// Ship apsides
String periapsis_s;
String apoapsis_s;
// Ship altitude
String alt_sea_s;
String alt_sur_s;
// Throttle motor target: -1 = no action, 0-1024 = target position
sword throttle_motorTarget_sw = -1;
word throttle_sliderMax_w = 1023;
word throttle_sliderMin_w = 0;
// -----------------

void setup()
{
  // Open the serial connection.
  Serial.begin(115200);

  // ---- IO initialization ----

  // Setup the build in LED, and turn it on.
  pinMode(LED_BUILTIN, OUTPUT);
  digitalWrite(LED_BUILTIN, HIGH);

  // Setup the RCS and SAS LEDs.
  pinMode(RCS_LED_PIN, OUTPUT);
  digitalWrite(RCS_LED_PIN, LOW);
  pinMode(SAS_LED_PIN, OUTPUT);
  digitalWrite(SAS_LED_PIN, LOW);

  // Setup digital gauges latch pin
  pinMode(DGAUGES_LATCH_PIN, OUTPUT);
  digitalWrite(DGAUGES_LATCH_PIN, HIGH);

  // Setup throttle motor pins
  pinMode(THROTTLE_MOT_FWD_PIN, OUTPUT);
  pinMode(THROTTLE_MOT_REV_PIN, OUTPUT);
  pinMode(THROTTLE_INPUT_PIN, INPUT);
  /* DEBUG TODO RM*/
  pinMode(pb1, INPUT);
  pinMode(pb2, INPUT);

  // Setup SPI for the digital gauges / LCD display
  SPI.begin();
  SPI.beginTransaction(dgaugesSpi);

  // Setup analog gauge
  pinMode(AGAUGE_EC_PIN, OUTPUT);
  // ----------------------------


  // ---- Subsystems initialization ----
  
  // Gauges init
  //dGaugesManagement();
  aGaugeManagement();

  // LCD Display init
  u8g2.begin();
  pinMode(LCD_DISPLAY_MODE_UP_PIN, INPUT_PULLUP);
  pinMode(LCD_DISPLAY_MODE_DOWN_PIN, INPUT_PULLUP);
  attachInterrupt(digitalPinToInterrupt(LCD_DISPLAY_MODE_UP_PIN), lcdDisplayModeUp, FALLING);
  attachInterrupt(digitalPinToInterrupt(LCD_DISPLAY_MODE_DOWN_PIN), lcdDisplayModeDown, FALLING);
  lcdDisplayManagement();
  // ----------------------------------

  // Throttle motor init
  throttleCalibration();

  // ---- KerbalSimpit initialization ----

  // This loop continually attempts to handshake with the plugin.
  // It will keep retrying until it gets a successful handshake.
  while (!simpitClient.init())
  {
    delay(100);
  }
  // Display a message on the LCD display to indicate handshaking is complete.
  lcdDisplayMode_sb = LCD_DISPLAY_MODE_APSIDES;
  lcdDisplayManagement();

  // Turn off the built-in LED to indicate handshaking is complete.
  digitalWrite(LED_BUILTIN, LOW);

  // Display a message in KSP to indicate handshaking is complete.
  simpitClient.printToKSP("Launchpad connected", PRINT_TO_SCREEN);

  // Sets our callback function. The KerbalSimpit library will
  // call this function every time a packet is received.
  simpitClient.inboundHandler(messageHandler);

  // Register SAS Mode channel.
  simpitClient.registerChannel(SAS_MODE_INFO_MESSAGE);

  // Register Oxidizer channel.
  simpitClient.registerChannel(OX_MESSAGE);

  // Register Apoapsis / Periapsis channel.
  simpitClient.registerChannel(APSIDES_MESSAGE);

  // Register Altitude channel.
  simpitClient.registerChannel(ALTITUDE_MESSAGE);

  // Register Electric charge channel.
  simpitClient.registerChannel(ELECTRIC_MESSAGE);

  // Register Scene change channel.
  //simpitClient.registerChannel(SCENE_CHANGE_MESSAGE);
  // -------------------------------------
}

dword loopCount_dw = 0;

void loop()
{
  // Check for new serial messages.
  simpitClient.update();
  
  // subsystems management
  //joystickManagement();
  throttleManagement();
  //dGaugesManagement();
  aGaugeManagement();
  if(loopCount_dw % 2500 == 0)
    lcdDisplayManagement();

  loopCount_dw++;
}

void joystickManagement()
{
  rotationMessage rotationMsg;

  // Read the joystick position from the potentiometers.
  // Rotation joystick
  int joyXRead = analogRead(JOY1_X_PIN);
  int joyYRead = analogRead(JOY1_Y_PIN);
  int joyZRead = analogRead(JOY1_Z_PIN);

  // Scale the joystick values to the range of a signed 16-bit integer and
  // apply a deadzone.
  int scaledX = map(joyYRead, 0, 1023, INT16_MIN, INT16_MAX);
  if (scaledX < JOY_DEADZONE && scaledX > -JOY_DEADZONE)
  {
    scaledX = 0;
  }
  int scaledY = map(joyXRead, 0, 1023, INT16_MIN, INT16_MAX);
  if (scaledY < JOY_DEADZONE && scaledY > -JOY_DEADZONE)
  {
    scaledY = 0;
  }
  int scaledZ = map(joyZRead, 0, 1023, INT16_MIN, INT16_MAX);
  if (scaledZ < JOY_DEADZONE && scaledZ > -JOY_DEADZONE)
  {
    scaledZ = 0;
  }

  // Set the rotation message
  rotationMsg.mask = PITCH_ROT | YAW_ROT | ROLL_ROT;
  rotationMsg.setPitch(scaledX);
  rotationMsg.setYaw(scaledY);
  rotationMsg.setRoll(scaledZ);

  // Send the message
  simpitClient.send(ROTATION_MESSAGE, rotationMsg);
}

void throttleManagement()
{
  throttleMessage throttleMsg;
  
  // Read the throttle position from the potentiometer.
  word throttleRead_w = analogRead(THROTTLE_INPUT_PIN);
  // Scale the throttle value to the range of a signed 16-bit integer.
  throttleMsg.throttle = map(throttleRead_w, 0, 1023, 0, INT16_MAX);
  // Send the message
  simpitClient.send(THROTTLE_MESSAGE, throttleMsg);

  // Throttle motor management
  if (digitalRead(pb1) == HIGH)
  {
    throttle_motorTarget_sw = throttle_sliderMax_w;
  }
  else if (digitalRead(pb2) == HIGH)
  {
    throttle_motorTarget_sw = throttle_sliderMin_w;
  }

  // Capacitive touch safety
  long cap = throttleTouchSensor.capacitiveSensor(30);
  if (cap >= THROTTLE_TOUCH_THRESHOLD)
  {
    // Turn off motor
    analogWrite(THROTTLE_MOT_FWD_PIN, LOW);
    analogWrite(THROTTLE_MOT_REV_PIN, LOW);
    throttle_motorTarget_sw = -1;
  }

  if(throttle_motorTarget_sw != -1)
  {
    if(throttleRead_w != throttle_motorTarget_sw)
    {
      if (throttleRead_w > throttle_motorTarget_sw)
      {
        analogWrite(THROTTLE_MOT_FWD_PIN, LOW);
        analogWrite(THROTTLE_MOT_REV_PIN, THROTTLE_MOT_TORQUE);
      }
      else
      {
        analogWrite(THROTTLE_MOT_FWD_PIN, THROTTLE_MOT_TORQUE);
        analogWrite(THROTTLE_MOT_REV_PIN, LOW);
      }
    }
    else
    {
      // Turn off motor
      analogWrite(THROTTLE_MOT_FWD_PIN, LOW);
      analogWrite(THROTTLE_MOT_REV_PIN, LOW);
      throttle_motorTarget_sw = -1;
    }
  }
}

void throttleCalibration()
{
  // Set the capacitive touch sensor to never re-calibrate.
  throttleTouchSensor.set_CS_AutocaL_Millis(0xFFFFFFFF);
  throttleTouchSensor.set_CS_Timeout_Millis(10);

  // Move the throttle to the maximum position.
  analogWrite(THROTTLE_MOT_FWD_PIN, THROTTLE_MOT_TORQUE);
  analogWrite(THROTTLE_MOT_REV_PIN, LOW);
  // Wait for the throttle to reach the maximum position.
  delay(350u);
  // Read the throttle position from the potentiometer.
  throttle_sliderMax_w = analogRead(THROTTLE_INPUT_PIN);
  // Move the throttle to the minimum position.
  analogWrite(THROTTLE_MOT_FWD_PIN, LOW);
  analogWrite(THROTTLE_MOT_REV_PIN, THROTTLE_MOT_TORQUE);
  // Wait for the throttle to reach the minimum position.
  delay(350u);
  // Read the throttle position from the potentiometer.
  throttle_sliderMin_w = analogRead(THROTTLE_INPUT_PIN);
  // Turn off the motor.
  analogWrite(THROTTLE_MOT_FWD_PIN, LOW);
  analogWrite(THROTTLE_MOT_REV_PIN, LOW);
}

#define DGAUGE_NORMAL 0
#define DGAUGE_BLINK  1
#define DGAUGE_DIM    2
#define DGAUGE_OFF    3

    // Digital gauges management
    void dGaugesManagement()
{
  static word dGaugeMgmtCallCount = 0;
  byte dgaugeMode_ba[NB_DGAUGES] = {DGAUGE_NORMAL};
  byte dgaugeBrightness_ba[NB_DGAUGES] = {100};
  byte fuelNbLedOn_ba[NB_DGAUGES] = {0};
  word fuelGaugesBitmask_wa[NB_DGAUGES] = {0};

  for(int i = 0; i < NB_DGAUGES; i++)
  {
    if(shipFuelPercent_ba[i] < 1) // If fuel is empty, turn off the gauge
    {
      dgaugeMode_ba[i] = DGAUGE_OFF;
    }
    else if (shipFuelPercent_ba[i] < 10) // If total fuel is under 10%, blink the gauge
    {
      dgaugeMode_ba[i] = DGAUGE_BLINK;
    }
    else // Otherwise, dim the curent led progressively
    {
      dgaugeMode_ba[i] = DGAUGE_DIM;
      dgaugeBrightness_ba[i] = 10 - (shipFuelPercent_ba[i] % 10);
    }

    // Get the number of leds to light up
    fuelNbLedOn_ba[i] = ceil(((double)shipFuelPercent_ba[i] / 10.0));
    
    // Build the bitmask
    for(int j = 0; j < fuelNbLedOn_ba[i]; j++)
    {
      fuelGaugesBitmask_wa[i] |= (1 << j);
    }
  }

  // Un-latch the shift registers
  digitalWrite(DGAUGES_LATCH_PIN, LOW);
  // Send the message to the shift registers via SPI
  for(int i = 0; i < NB_DGAUGES; i++)
  {
    if(dgaugeMode_ba[i] == DGAUGE_DIM)
    {
      if ((dGaugeMgmtCallCount/1) % (dgaugeBrightness_ba[i]) && dgaugeBrightness_ba[i] != 10)
      {
        fuelGaugesBitmask_wa[i] = fuelGaugesBitmask_wa[i] >> 1;
      }
    }
    else if (dgaugeMode_ba[i] == DGAUGE_BLINK)
    {
      if ((dGaugeMgmtCallCount/1000) % 2)
      {
        fuelGaugesBitmask_wa[i] = 0;
      }
    }
    else if (dgaugeMode_ba[i] == DGAUGE_OFF)
    {
      fuelGaugesBitmask_wa[i] = 0;
    }

    SPI.transfer(highByte(fuelGaugesBitmask_wa[i]));
    SPI.transfer(lowByte(fuelGaugesBitmask_wa[i]));
  }
  // latch the shift registers
  digitalWrite(DGAUGES_LATCH_PIN, HIGH);

  dGaugeMgmtCallCount++;
}

void lcdDisplayManagement(void)
{
  u8g2.clearBuffer();

  switch (lcdDisplayMode_sb)
  {
  case LCD_DISPLAY_MODE_IDLE:
    sprintf(lcdLine1_ba, "KSP Launchpad");
    sprintf(lcdLine2_ba, "Disconnected");

    u8g2.setFont(u8g2_font_9x18_tf);
    u8g2.drawStr(0, 18, lcdLine1_ba);
    u8g2.setFont(u8g2_font_7x13_tf);
    u8g2.drawStr(20, 31, lcdLine2_ba);
    break;

  case LCD_DISPLAY_MODE_CONNECTED:
    sprintf(lcdLine1_ba, "KSP Launchpad");
    sprintf(lcdLine2_ba, "Connected");

    u8g2.setFont(u8g2_font_9x18_tf);
    u8g2.drawStr(0, 18, lcdLine1_ba);
    u8g2.setFont(u8g2_font_7x13_tf);
    u8g2.drawStr(20, 31, lcdLine2_ba);
    break;

  case LCD_DISPLAY_MODE_APSIDES:
    apoapsis_s.toCharArray(lcdLine1_ba, 16);
    periapsis_s.toCharArray(lcdLine2_ba, 16);

    u8g2.setFont(u8g2_font_8x13_mf);
    u8g2.drawStr(0, 13, lcdLine1_ba);
    u8g2.drawStr(0, 30, lcdLine2_ba);
    break;

  case LCD_DISPLAY_MODE_ALT:
    alt_sea_s.toCharArray(lcdLine1_ba, 16);
    alt_sur_s.toCharArray(lcdLine2_ba, 16);

    u8g2.setFont(u8g2_font_8x13_mf);
    u8g2.drawStr(0, 13, lcdLine1_ba);
    u8g2.drawStr(0, 30, lcdLine2_ba);
    break;
  
  default:
    break;
  }
  u8g2.sendBuffer();
}

void messageHandler(byte messageType, byte msg[], byte msgSize)
{
  switch (messageType)
  {
    case SAS_MODE_INFO_MESSAGE:
      // Checking if the message is the size we expect is a very basic
      // way to confirm if the message was received properly.
      if (msgSize == sizeof(SASInfoMessage))
      {
        // Create a new SASInfoMessage struct
        SASInfoMessage sasInfo;
        // Convert the message we received to an SASInfoMessage struct.
        sasInfo = parseMessage<SASInfoMessage>(msg);
        // Turn the LED on if SAS is enabled Otherwise turn it off.
        if (sasInfo.currentSASMode != 255)
        {
          digitalWrite(SAS_LED_PIN, HIGH);
        }
        else
        {
          digitalWrite(SAS_LED_PIN, LOW);
        }
      }
    break;

    case OX_MESSAGE:
      // Checking if the message is the size we expect is a very basic
      // way to confirm if the message was received properly.
      if (msgSize == sizeof(resourceMessage))
      {
        // Create a new resourceMessage struct
        resourceMessage oxInfo;
        // Convert the message we received to an resourceMessage struct.
        oxInfo = parseMessage<resourceMessage>(msg);
        shipFuelPercent_ba[DGAUGES_OX] = (byte)map(oxInfo.available, 0, oxInfo.total, 0, 100);
      }
    break;

    case ELECTRIC_MESSAGE:
      // Checking if the message is the size we expect is a very basic
      // way to confirm if the message was received properly.
      if (msgSize == sizeof(resourceMessage))
      {
        // Create a new resourceMessage struct
        resourceMessage electricInfo;
        // Convert the message we received to an resourceMessage struct.
        electricInfo = parseMessage<resourceMessage>(msg);
        shipECPercent_b = (byte)map(electricInfo.available, 0, electricInfo.total, 0, 255);
      }
      break;

    case APSIDES_MESSAGE:
      // Checking if the message is the size we expect is a very basic
      // way to confirm if the message was received properly.
      if (msgSize == sizeof(apsidesMessage))
      {
        // Convert the message we received to an apsidesMessage struct.
        apsidesMessage apsides_s;
        apsides_s = parseMessage<apsidesMessage>(msg);

        String apo_string = "A:";
        String peri_string = "P:";

        float apoapsis = apsides_s.apoapsis;
        float periapsis = apsides_s.periapsis;

        if (abs(apoapsis) < 5000)
        {
          apoapsis_s = apo_string + apoapsis + "m";
        }
        else if ((abs(apoapsis) >= 5000) && (apoapsis < pow(10, 6)))
        {
          apoapsis_s = apo_string + apoapsis / pow(10, 3) + "Km";
        }
        else
        {
          apoapsis_s = apo_string + apoapsis / pow(10, 6) + "Mm";
        }

        if (abs(periapsis) < 5000)
        {
          periapsis_s = peri_string + periapsis + "m";
        }
        else if ((abs(periapsis) >= 5000) && (periapsis < pow(10, 6)))
        {
          periapsis_s = peri_string + periapsis / pow(10, 3) + "Km";
        }
        else
        {
          periapsis_s = peri_string + periapsis / pow(10, 6) + "Mm";
        }
      }
    break;

    case ALTITUDE_MESSAGE:
      // Checking if the message is the size we expect is a very basic
      // way to confirm if the message was received properly.
      if (msgSize == sizeof(altitudeMessage))
      {
        // Convert the message we received to an altitudeMessage struct.
        altitudeMessage altitude_s;
        altitude_s = parseMessage<altitudeMessage>(msg);

        String altitude_sea_string = "Sea:";
        String altitude_surface_string = "Gnd:";
        float alt_sea = altitude_s.sealevel;
        float alt_sur = altitude_s.surface;

        if (abs(alt_sea) < 5000)
        {
          alt_sea_s = altitude_sea_string + alt_sea + "m";
        }
        else if ((abs(alt_sea) >= 5000) && (alt_sea < pow(10, 6)))
        {
          alt_sea_s = altitude_sea_string + alt_sea / pow(10, 3) + "Km";
        }
        else
        {
          alt_sea_s = altitude_sea_string + alt_sea / pow(10, 6) + "Mm";
        }

        if (abs(alt_sur) < 5000)
        {
          alt_sur_s = altitude_surface_string + alt_sur + "m";
        }
        else if ((abs(alt_sur) >= 5000) && (alt_sur < pow(10, 6)))
        {
          alt_sur_s = altitude_surface_string + alt_sur / pow(10, 3) + "Km";
        }
        else
        {
          alt_sur_s = altitude_surface_string + alt_sur / pow(10, 6) + "Mm";
        }
      }
    break;
    default:
    break;
  }
}

void lcdDisplayModeUp(void)
{
  static unsigned long last_interrupt_time = 0;
  unsigned long interrupt_time = millis();
  // debounce
  if (interrupt_time - last_interrupt_time > 350)
  {
    last_interrupt_time = interrupt_time;
    lcdDisplayMode_sb++;
    if (lcdDisplayMode_sb > NB_LCD_DISPLAY_MODES - 1)
    {
      lcdDisplayMode_sb = 0;
    }
  }
}

void lcdDisplayModeDown(void)
{
  static unsigned long last_interrupt_time = 0;
  unsigned long interrupt_time = millis();
  // debounce
  if(interrupt_time - last_interrupt_time > 350)
  {
    if (lcdDisplayMode_sb == 0)
    {
      lcdDisplayMode_sb = NB_LCD_DISPLAY_MODES - 1;
    }
    else
    {
      lcdDisplayMode_sb--;
    }
  }
}

void aGaugeManagement(void)
{
  analogWrite(AGAUGE_EC_PIN, shipECPercent_b);
}

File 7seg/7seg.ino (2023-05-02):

// https://forum.arduino.cc/index.php?topic=518797.0
// ST_CP = SCK
// SH_CP = RCK
// SDI   = DIO
// Common anode
#define DIO 12
#define SCK 15
#define RCK 14
#define SPEED 500

boolean numbersDef[10][8] = 
{
  {1,1,1,1,1,1,0}, //zero
  {0,1,1,0,0,0,0}, //one
  {1,1,0,1,1,0,1}, //two
  {1,1,1,1,0,0,1}, //three
  {0,1,1,0,0,1,1}, //four
  {1,0,1,1,0,1,1}, //five
  {1,0,1,1,1,1,1}, //six
  {1,1,1,0,0,0,0}, //seven
  {1,1,1,1,1,1,1}, //eight
  {1,1,1,1,0,1,1}  //nine
};

boolean digitsTable[8][8] =
{
  {0,0,0,0,1,0,0,0}, // first digit
  {0,0,0,0,0,1,0,0}, // second
  {0,0,0,0,0,0,1,0}, // third
  {0,0,0,0,0,0,0,1},  // 8th 
  {1,0,0,0,0,0,0,0}, // forth
  {0,1,0,0,0,0,0,0}, // fifth
  {0,0,1,0,0,0,0,0},  // sixth  
  {0,0,0,1,0,0,0,0} // 7th
};

void setup() {
  pinMode(DIO, OUTPUT);
  pinMode(SCK, OUTPUT);
  pinMode(RCK, OUTPUT);
  digitalWrite(DIO, LOW);
  digitalWrite(SCK, LOW);
  digitalWrite(RCK, LOW);
}

boolean display_buffer[32];

void prepareDisplayBuffer(int number, int digit_order, boolean showDot)
{
  for(int index=7; index>=0; index--)
  {
    display_buffer[index] = digitsTable[digit_order-1][index];
  }
  for(int index=14; index>=8; index--)
  {
    display_buffer[index] = !numbersDef[number-1][index]; //because logic is sanity, right?
  }
  if(showDot == true)
    display_buffer[15] = 0;
  else
    display_buffer[15] = 1;
}

void writeDigit(int number, int order, bool showDot = false)
{
  prepareDisplayBuffer(number, order, showDot);
  digitalWrite(RCK, LOW);
  for(int i=15; i>=0; i--)
  {
      digitalWrite(SCK, LOW);
      digitalWrite(DIO, display_buffer[i]); //output LOW - enable segments, HIGH - disable segments
      digitalWrite(SCK, HIGH);
   }
  digitalWrite(RCK, HIGH);
}

void writeNumber(double number, char nb_decimals = 0)
{
  long integer = (long)(number*(pow(10.0,(double)nb_decimals)));
  
  if(integer > 99999999)
  {
    integer = 99999999;
  }

  char digit = 8;
  while(digit > 0)
  {
    long mod = integer % 10;
    integer /= 10;
    writeDigit(mod, digit, 8-nb_decimals == digit);
    digit--;
  }
}

double num = 123.456;

void loop() {
  writeNumber(num,2);
  num = num + 0.0021;
}

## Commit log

2023-03-28 Fix typo in README.md: "Linaer" to "Linear" for throttle potentiometers
2023-03-28 Initial kicad files (wip)
    [launchpad.kicad_pcb, launchpad.kicad_sch]
2023-03-28 Readme for the schematics directory
2023-03-28 SCH: Gauges routing complete
    [launchpad.kicad_pcb, launchpad.kicad_sch]
2023-03-29 SCH: routing improvement
    +ground plane
    +via stiching
    [launchpad.kicad_pcb, launchpad.kicad_sch]
2023-03-29 Ignore new schematics/fab_out/ directory
2023-03-29 SCH: Mainboard wip
    [dgauges.kicad_pcb, dgauges.kicad_sch, mainboard.kicad_pcb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]
2023-03-29 SCH: mv sch to root dir / dgauges: GND plane filling, via stiching
    [dgauges.kicad_pcb, mainboard.kicad_pcb, mainboard.kicad_sch]
2023-03-30 SCH: dgauge => ust proper JST connector for J1
    [dgauges.kicad_pcb, dgauges.kicad_sch, mainboard.kicad_pcb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]
2023-03-30 Update README.md
    Led gauges
2023-04-03 SCH: DGauges: route serial out to header for daisy-chaining
    And add mounting holes
    [dgauges.kicad_pcb, dgauges.kicad_sch]
2023-04-03 SCH: tune mounting holes
    [dgauges.kicad_pcb]
2023-04-03 SCH: maionboard base, routing in progress
    [mainboard.kicad_pcb, mainboard.kicad_sch]
2023-04-03 SCH: mainboard: cont.
    [mainboard.kicad_pcb, mainboard.kicad_sch]
2023-04-04 SCH: mainboard=> +regu on VIN. routing cont.
    [mainboard.kicad_pcb, mainboard.kicad_sch]
2023-04-06 SCH: mainboard=> joy2 header + throttle header
    [mainboard.kicad_pcb, mainboard.kicad_sch]
2023-04-06 SCH: mainboard=> DGAUGES header
    [dgauges.kicad_pcb, dgauges.kicad_sch, mainboard.kicad_pcb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]
2023-04-06 SCH: dgauges=> set res. values to get similar brightness on all bars
    [dgauges.kicad_pcb, dgauges.kicad_sch]
2023-04-07 lcd : display apsides / altitudes.
    change mode with pin 2/3
2023-04-07 SCH: LCD
    [lcd.kicad_pcb, lcd.kicad_sch]
2023-04-07 SCH: LCD=> add pot for backlight brightness
    [lcd.kicad_pcb, lcd.kicad_sch]
2023-04-12 SCH: LCD=> Changed level shifter
    [lcd.kicad_pcb, lcd.kicad_sch]
2023-04-13 Mainboard: tweak pins, routed lcd connector
    [mainboard.kicad_pcb, mainboard.kicad_sch]
2023-04-13 Panels: control panel v1
    [controls.kicad_pcb, controls.kicad_sch]
2023-04-13 Panels: control panel v2 + SAS panel v1
    [controls.kicad_pcb, sas.kicad_pcb, sas.kicad_sch]
2023-04-17 Sch: gauges: add one for xenon
    [dgauges.kicad_pcb, dgauges.kicad_sch]
2023-04-17 Panels: rework of ctrl and sas. Add gauges and v1 of executive
    [controls.kicad_pcb, executive.kicad_pcb, executive.kicad_sch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]
2023-04-17 SCH: mainboard missing cap & gnd connections on ft232
    [mainboard.kicad_pcb, mainboard.kicad_sch]
2023-04-18 Panels: rounded iner edges for fab
    [controls.kicad_pcb, gauges.kicad_pcb]
2023-04-22 SCH: Mainboard: add power LED
    [mainboard.kicad_pcb, mainboard.kicad_sch]
2023-04-24 SCH: Mainboard=> LED routing (1)
    [mainboard.kicad_pcb, mainboard.kicad_sch]
2023-04-25 SCH: Mainboard=> LED/Buttons routing(2)
    [mainboard.kicad_pcb, mainboard.kicad_sch]
2023-04-25 Panels: adjusted toggle switches radius from real parts measurements
    [controls.kicad_pcb, executive.kicad_pcb, sas.kicad_pcb]
2023-04-25 SCH: MAinboard=> Clean DRC issues
    [mainboard.kicad_pcb, mainboard.kicad_sch]
2023-04-26 SCH: LCD=> fixes, production ready
    [lcd.kicad_pcb, lcd.kicad_sch]
2023-04-28 SCH:MB=> fixes + gen jlc fab prj
    [mainboard.kicad_pcb, mainboard.kicad_sch]
2023-04-28 SCH:MB=> Changed FT232 package
    [mainboard.kicad_pcb]
2023-04-28 SCH:MB=> add pull-up to throttle signals
    [mainboard.kicad_pcb, mainboard.kicad_sch]
2023-05-01 Sw: Throttle: motorized slider mgmt, capacitive touch safety
2023-05-07 SCH:MB=> moved decoupling caps to each +5V on the ATMega
    [mainboard.kicad_pcb, mainboard.kicad_sch]
2023-05-08 Panels: changed height to 100mm, need to align & anotate 7-seg display
    [gauges.kicad_pcb, seven-seg.kicad_pcb, seven-seg.kicad_sch]
2023-05-10 Panels: added M4 mounting holes
    [controls.kicad_pcb, executive.kicad_pcb, gauges.kicad_pcb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]
2023-05-18 SCH: LCD => removed MB OE connection, now pulled to 3.3, always ON
    [lcd.kicad_pcb, lcd.kicad_sch, mainboard.kicad_pcb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]
2023-05-22 panels: gauges=> aligned mounting holes
    [dgauges.kicad_pcb, gauges.kicad_pcb]
